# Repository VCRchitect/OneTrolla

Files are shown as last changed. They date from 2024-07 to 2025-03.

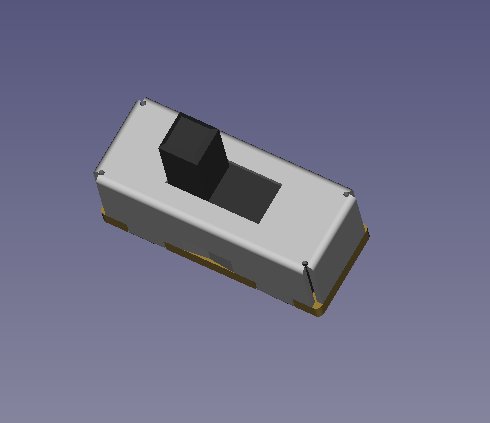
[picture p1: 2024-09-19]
KiCad Files/3D Models/ss12d00-1.snapshot.10/SS12D00 view 2.jpg

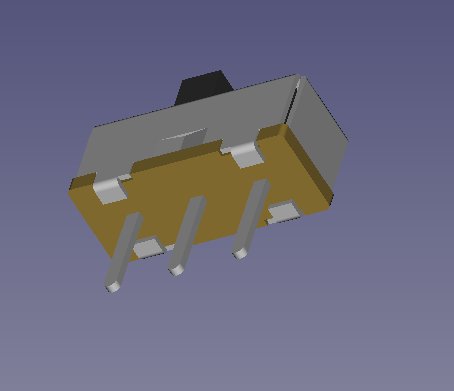
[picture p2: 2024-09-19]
KiCad Files/3D Models/ss12d00-1.snapshot.10/SS12D00 view3.jpg

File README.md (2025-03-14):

This is an ongoing project that aims to create a cheap, easy-to-use controller for those that have the usage of only one hand. 

The controller uses a custom circuit board that is paired with an Arduino Pro Micro and an MPU6050 Accelerometer. It has full compatibility as a wired controller for the Nintendo Switch, PC (including STEAM), Steam Deck, and Android phones (with an OTG cable or adapter).

HOW DO I USE IT?

The single analog stick on the device will act as either the left analog stick or right analog stick of a controller, depending on which mode you're in. The other stick will be controlled via motion and the accelerometer.

You can tilt the controller as if it were an arcade stick and it will act accordingly. I have inverted up and down on the left stick because, through my playtesting, it feels more natural to run forward by lifting up the controller. Not many games require running backwards, so pressing down is tilting forward, which feels less natural and, therefore, less used.

To quickly and easily swap which stick is which, press the button on the very bottom right of the controller (while you're looking directly at the buttons).

The buttons are arranged in a + pattern, just like most modern controllers. Top is X, left is Y, right is A, down is B, just like the Nintendo Switch. The two buttons below are the left trigger and right trigger.

In order to access the secondary buttons, hold down a primary button. X is Start, Y is R3, A is L3, B is Select, left trigger is LB, and right trigger is RB. If you are playing a game that requires holding a button that is considered a "primary" button, press it repeatedly and it will register as being consistently held.

To use the DPAD, press the physical analog stick in and tilt the analog stick in a direction to press the corresponding DPAD button.

The bottom left button (when you're looking directly at the buttons) is the HOME button. Tap it repeatedly to bring up the sleep menu. If you hold the HOME button until the LED changes, it will turn off the toggle function, making all the buttons function exactly the same as each other.

The toggles are for left trigger, right trigger, L3, and R3, which are buttons that are often held. Games like Zelda make this a necessity. Games like Mario 64 don't need the toggles, so they're easy to turn off.

Speaking of turning things off, it's easy to turn off the accelerometer and just use the stick for more basic games. You simply flip the physical toggle switch to the left of the B button.

If this isn't making as much sense as I'd like, review this image (some slight differences may be here because of more recent board revisions):

OneTrollaV3 Control Guide

If that still doesn't make any sense, please check out this vide (with timestamps!) that I made to explain everything and show off some gameplay:

https://youtu.be/NdQK882Hlzc?si=iMgsrqBHt_KTq-6e

Thanks for checking out the project!

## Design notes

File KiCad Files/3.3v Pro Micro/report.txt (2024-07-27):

Plotted to 'C:\Users\User\Desktop\Custom Duino\3.3v Pro Micro-F_Cu.gbr'.
Plotted to 'C:\Users\User\Desktop\Custom Duino\3.3v Pro Micro-B_Cu.gbr'.
Plotted to 'C:\Users\User\Desktop\Custom Duino\3.3v Pro Micro-F_Paste.gbr'.
Plotted to 'C:\Users\User\Desktop\Custom Duino\3.3v Pro Micro-B_Paste.gbr'.
Plotted to 'C:\Users\User\Desktop\Custom Duino\3.3v Pro Micro-F_Silkscreen.gbr'.
Plotted to 'C:\Users\User\Desktop\Custom Duino\3.3v Pro Micro-B_Silkscreen.gbr'.
Plotted to 'C:\Users\User\Desktop\Custom Duino\3.3v Pro Micro-F_Mask.gbr'.
Plotted to 'C:\Users\User\Desktop\Custom Duino\3.3v Pro Micro-B_Mask.gbr'.
Plotted to 'C:\Users\User\Desktop\Custom Duino\3.3v Pro Micro-Edge_Cuts.gbr'.
Created Gerber job file 'C:\Users\User\Desktop\Custom Duino\3.3v Pro Micro-job.gbrjob'.
Info: Done.

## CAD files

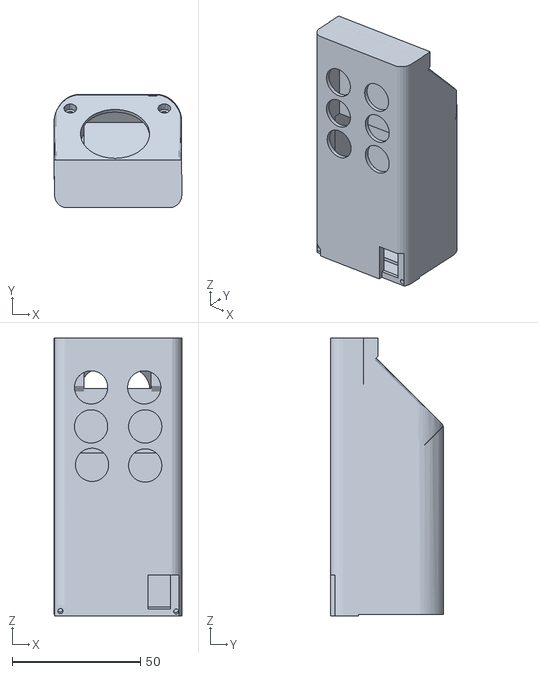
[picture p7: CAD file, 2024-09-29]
3D Print Files/Assembled Shell Render.stl
49.9 x 44.2 x 108.6

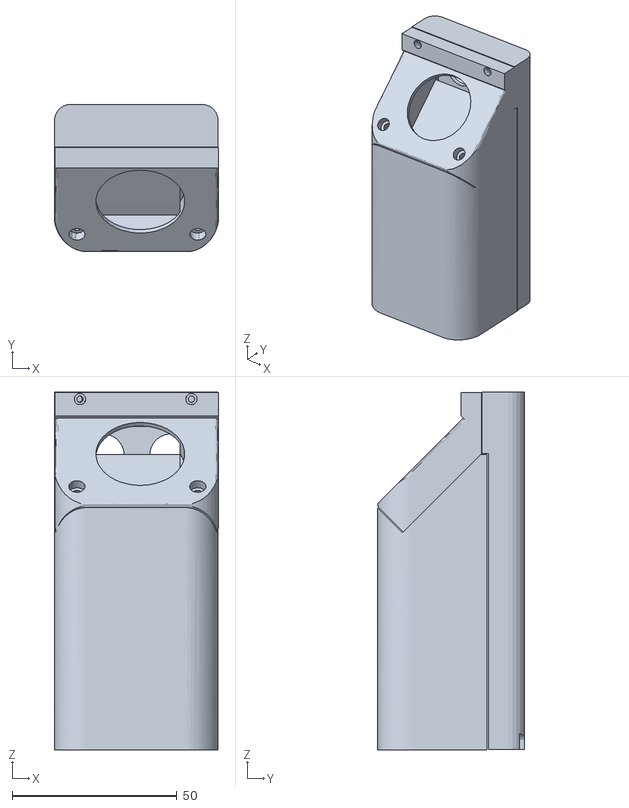
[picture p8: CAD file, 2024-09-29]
3D Print Files/Full Render.stl
49.8 x 44.6 x 108.7

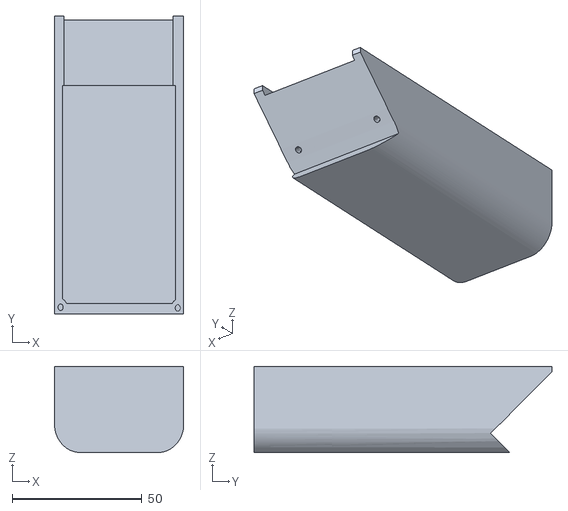
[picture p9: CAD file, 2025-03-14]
3D Print Files/OneTrollaV4 Back Plate.stl
49.8 x 114.9 x 33.2

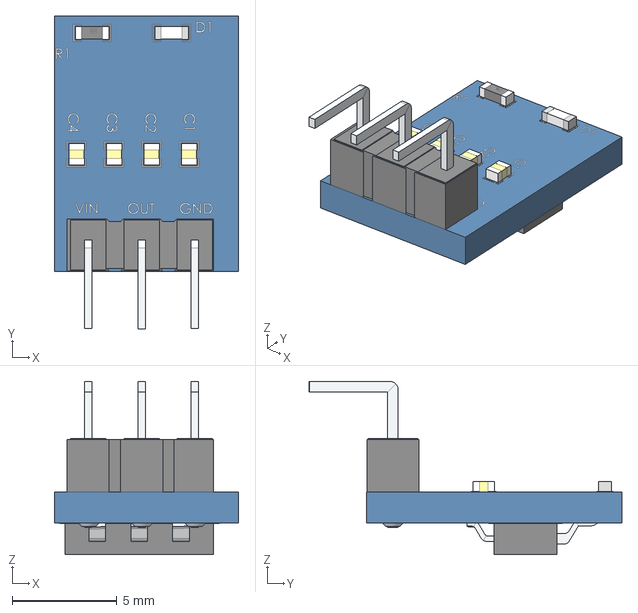
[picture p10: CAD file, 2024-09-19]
KiCad Files/3D Models/ams1117-1.snapshot.3/Regulador AMS1117 5V a 3.step
8.80 x 14.9 x 8.28 mm

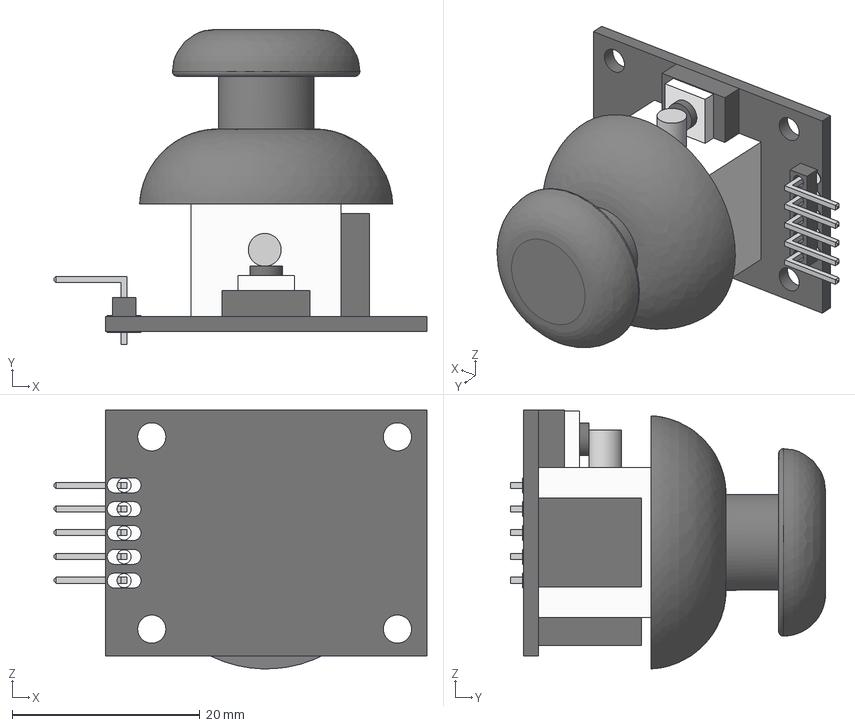
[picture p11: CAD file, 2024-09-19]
KiCad Files/3D Models/joy-stick-4.snapshot.1/joy_stick_a2/joy_stick_a2.iges
39.8 x 33.6 x 27.6 mm

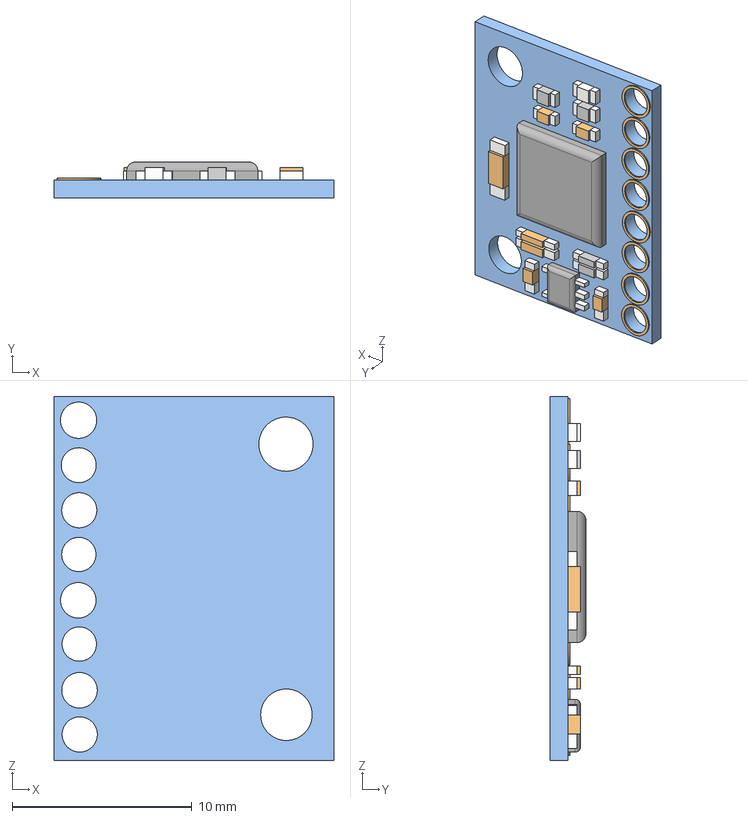
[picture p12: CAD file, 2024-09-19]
KiCad Files/3D Models/mpu6050-8.snapshot.1/MPU6050 v2.step
15.6 x 2.00 x 20.3 mm

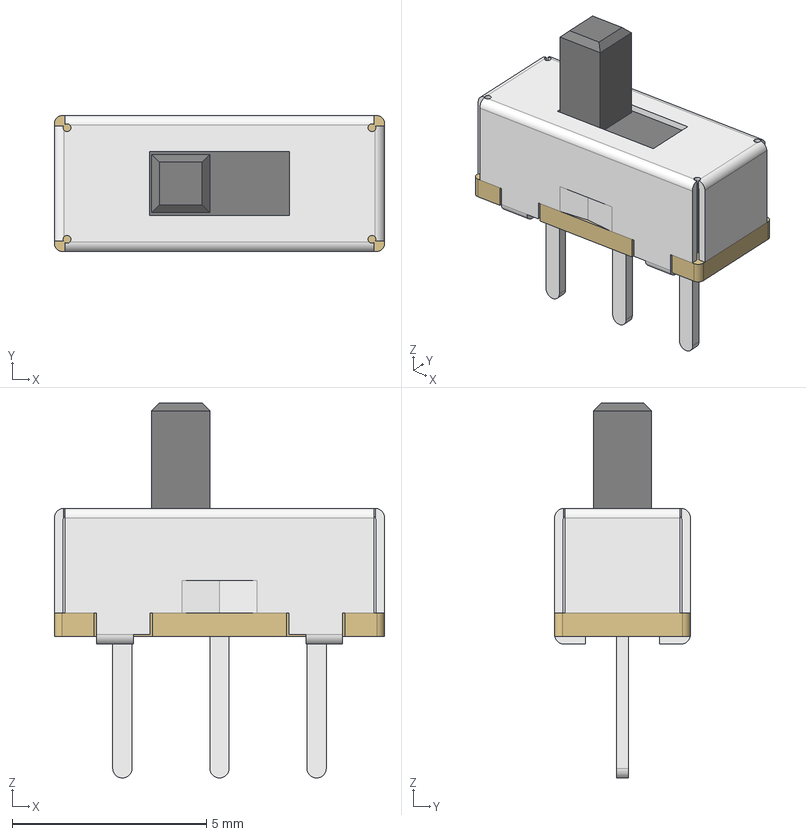
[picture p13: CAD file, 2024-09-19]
KiCad Files/3D Models/ss12d00-1.snapshot.10/SPDT slide switch SS12D00.step
8.50 x 3.50 x 9.66 mm

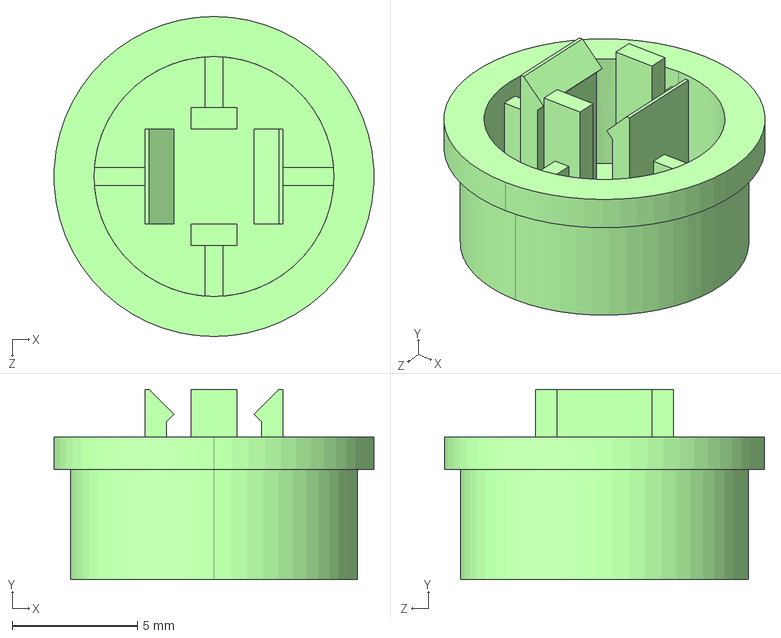
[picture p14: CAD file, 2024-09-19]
KiCad Files/3D Models/Tactile Push Button B3F-405 12X12x7.3mm with Cap/Tactile Button Cap for B3F-4055 12X12X7.3MM.STEP
12.8 x 7.60 x 12.8 mm

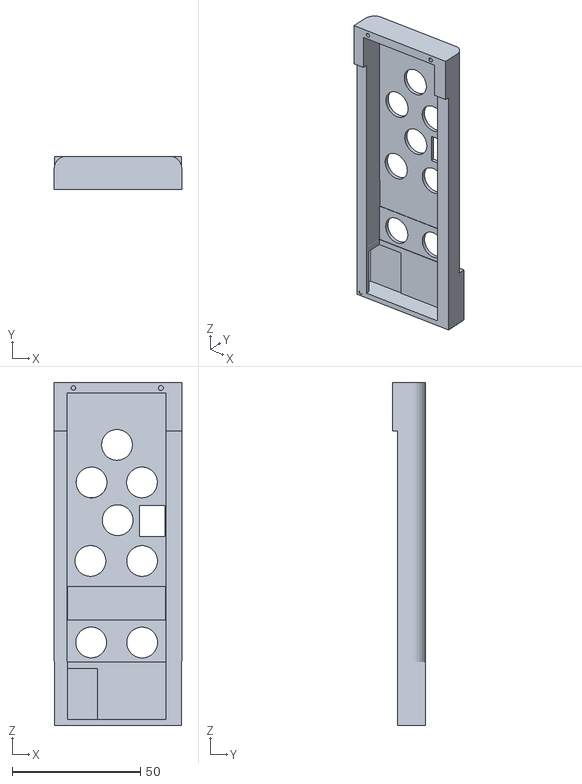
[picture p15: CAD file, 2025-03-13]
3D Print Files/OneTrollaV4 Front Plate.stl
49.8 x 12.8 x 133.5

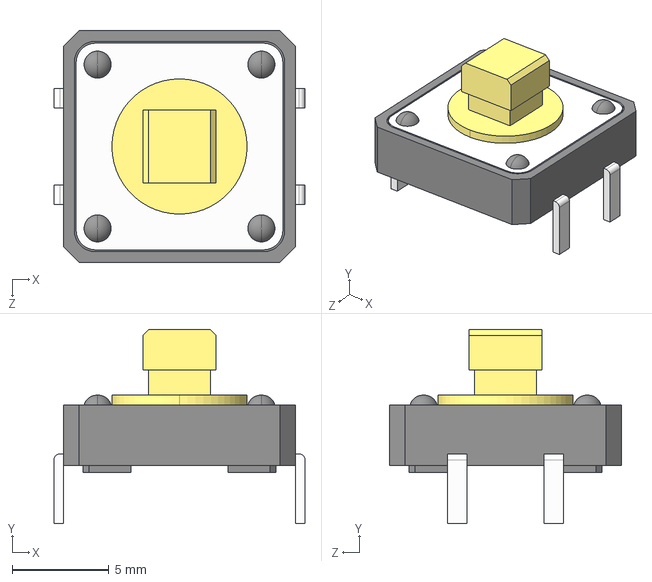
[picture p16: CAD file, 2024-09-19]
KiCad Files/3D Models/Tactile Push Button B3F-405 12X12x7.3mm with Cap/Tactile Push Button B3F-405 12X12x7.3mm.STEP
13.0 x 10.1 x 12.0 mm

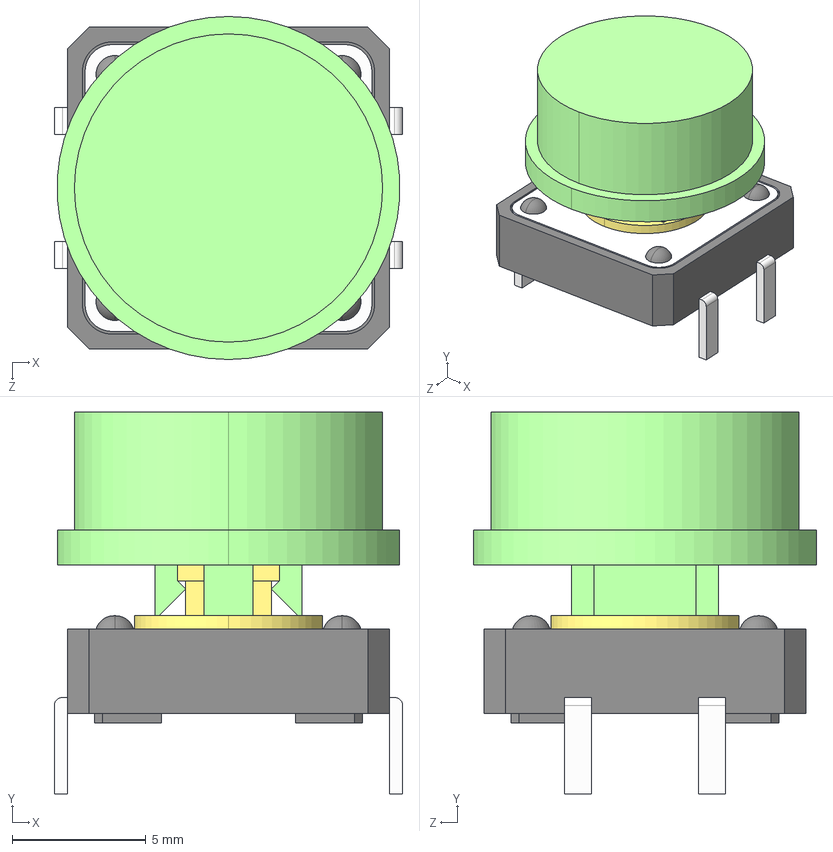
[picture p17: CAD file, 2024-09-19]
KiCad Files/3D Models/Tactile Push Button B3F-405 12X12x7.3mm with Cap/Push Button B3F-4055 with Cap.STEP
13.0 x 14.3 x 12.8 mm
Кнопка12х12х7,3
Tactile Button Caps for B3F-4055 12X12X7.3MM

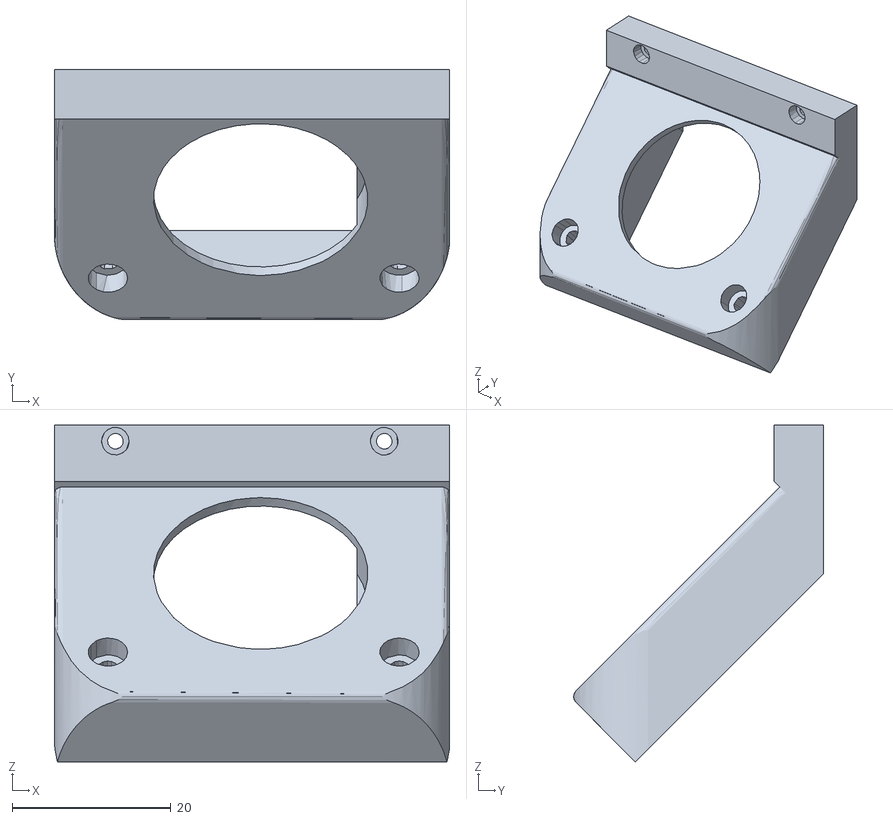
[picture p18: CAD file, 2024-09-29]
3D Print Files/OneTrollaV4 Joy Plate.stl
49.8 x 31.5 x 42.4

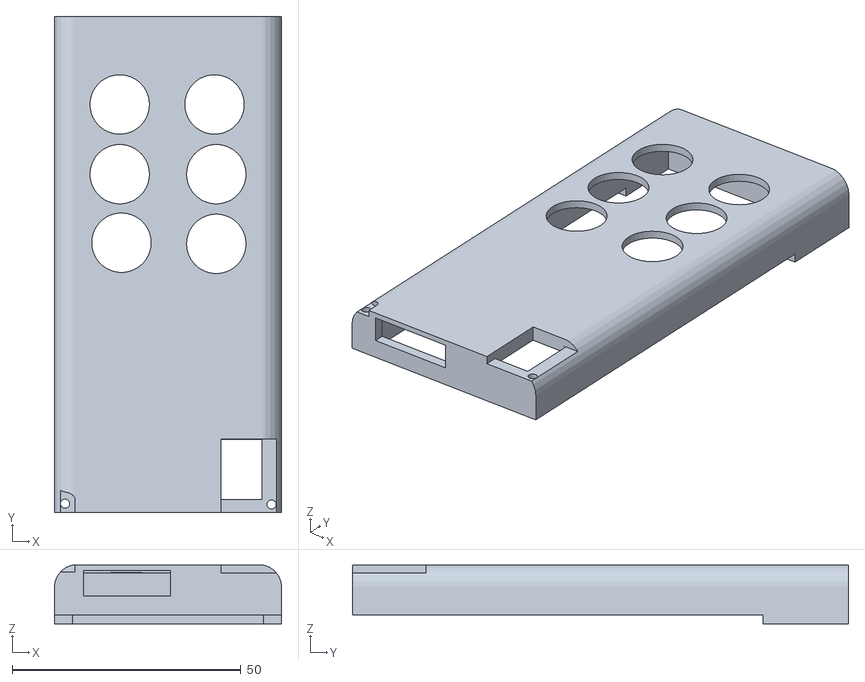
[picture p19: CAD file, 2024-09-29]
3D Print Files/Front Plate to be Edited.stl
49.8 x 108.5 x 12.9

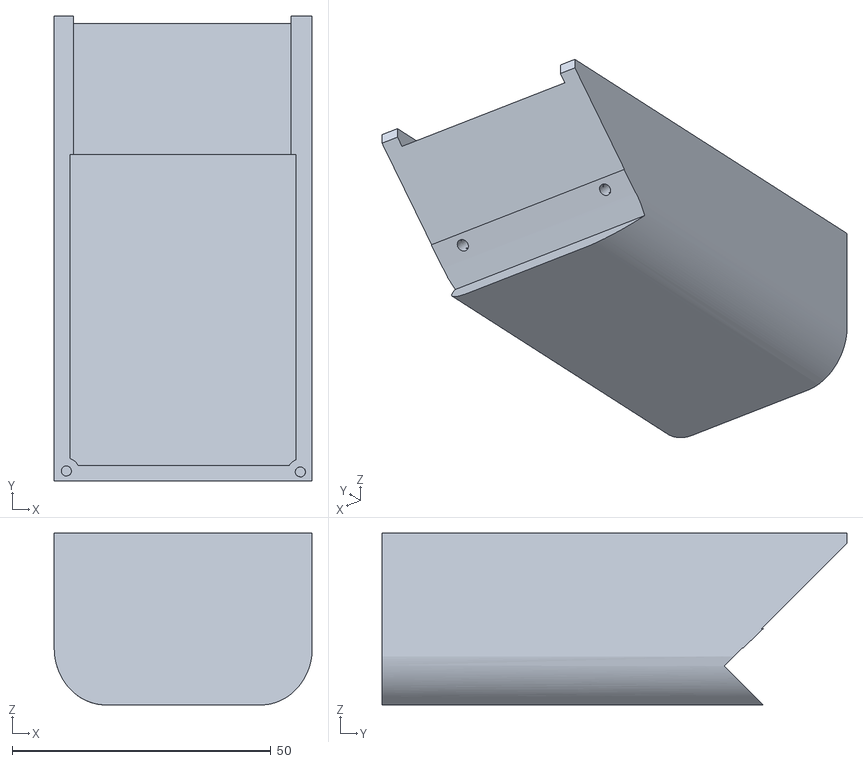
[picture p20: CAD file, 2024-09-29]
3D Print Files/Back Plate Paragon.stl
49.8 x 89.8 x 33.2

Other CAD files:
KiCad Files/3D Models/joy-stick-4.snapshot.1/joy_stick_a2/joy_stick_2a.step
KiCad Files/3D Models/Tactile Push Button B3F-405 12X12x7.3mm with Cap/Tactile Button Caps for B3F-4055 12X12X7.3MM.SLDPRT
KiCad Files/3D Models/Tactile Push Button B3F-405 12X12x7.3mm with Cap/Push Button B3F-4055 with Cap.SLDASM
KiCad Files/3D Models/Tactile Push Button B3F-405 12X12x7.3mm with Cap/Tactile Push Button B3F-405 12X12x7.3mm.SLDPRT
KiCad Files/3D Models/logic-level-converter-5v-to-3-3v-module-1.snapshot.1/Logi Level Converter.x_t
KiCad Files/3D Models/mpu6050-8.snapshot.1/MPU6050 v2.stl

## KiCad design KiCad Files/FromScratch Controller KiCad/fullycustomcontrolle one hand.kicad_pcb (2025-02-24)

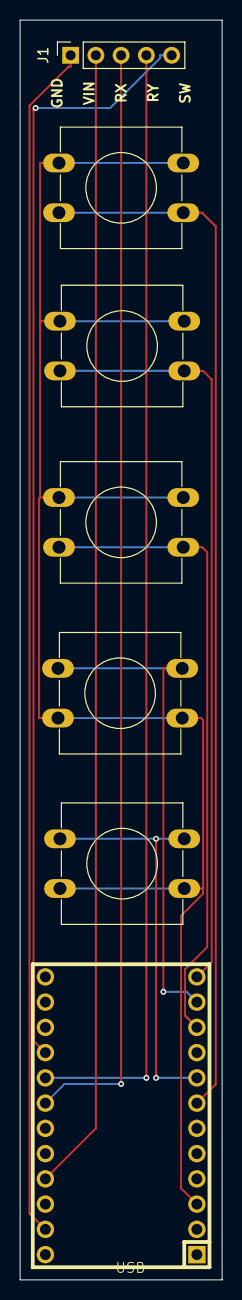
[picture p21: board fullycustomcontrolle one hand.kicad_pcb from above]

Board: 2 copper layers, 20.3 x 126.7 mm, 7 parts (0 on the bottom side), 11 nets.

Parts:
J1: Conn_01x05_Socket; PinSocket_1x05_P2.54mm_Vertical
SW2, SW3, SW4, SW6, SW7: SW_Omron_B3FS; SW_PUSH-12mm
U1: ProMicro; ARDUINO_PRO_MICRO

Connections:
unnamed: J1.1, U1.23 (GND)
unnamed: J1.2, U1.21 (VCC)
unnamed: J1.3, U1.18 (F6)
unnamed: J1.4, U1.17 (F7)
unnamed: J1.5, U1.16 (B1)
unnamed: SW2.2, SW3.2, SW4.2, SW6.2, SW7.2, U1.3 (GND)
unnamed: SW7.1, U1.11 (B4)
unnamed: SW3.1, U1.12 (B5)
unnamed: SW4.1, U1.8 (C6)
unnamed: SW2.1, U1.7 (D4)
unnamed: SW6.1, U1.10 (E6)

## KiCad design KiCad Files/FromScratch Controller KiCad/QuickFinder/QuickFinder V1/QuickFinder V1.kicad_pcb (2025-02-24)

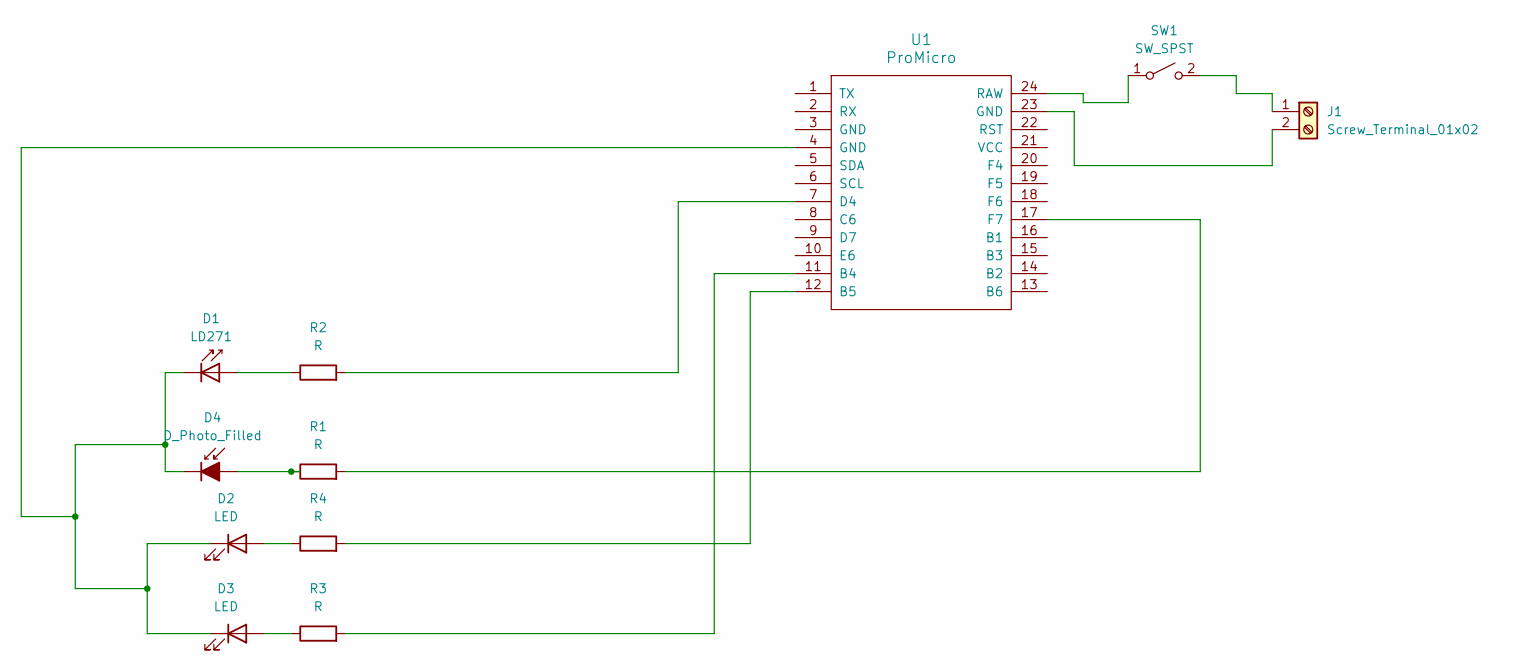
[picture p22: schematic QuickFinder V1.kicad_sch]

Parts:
D1: LD271; LED_D5.0mm_IRGrey
D2, D3: LED; LED_D3.0mm
D4: D_Photo_Filled; LED_D5.0mm
J1: Screw_Terminal_01x02; TerminalBlock_Phoenix_MPT-0,5-2-2.54_1x02_P2.54mm_Horizontal
R1, R2, R3, R4: R; R_Axial_DIN0207_L6.3mm_D2.5mm_P7.62mm_Horizontal
SW1: SW_SPST; SS12D00G SPDT Micro Switch
U1: ProMicro; ARDUINO_PRO_MICRO

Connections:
unnamed: D1.2 (A), R2.1
unnamed: D1.1 (K), D2.1 (K), D3.1 (K), D4.1 (K), U1.4 (GND)
unnamed: D2.2 (A), R4.1
unnamed: D3.2 (A), R3.1
unnamed: D4.2 (A), R1.1
unnamed: J1.1, SW1.2 (B)
unnamed: J1.2, U1.23 (GND)
unnamed: SW1.1 (A), U1.24 (RAW)
unnamed: R3.2, U1.11 (B4)
unnamed: R4.2, U1.12 (B5)
unnamed: R2.2, U1.7 (D4)
unnamed: R1.2, U1.17 (F7)

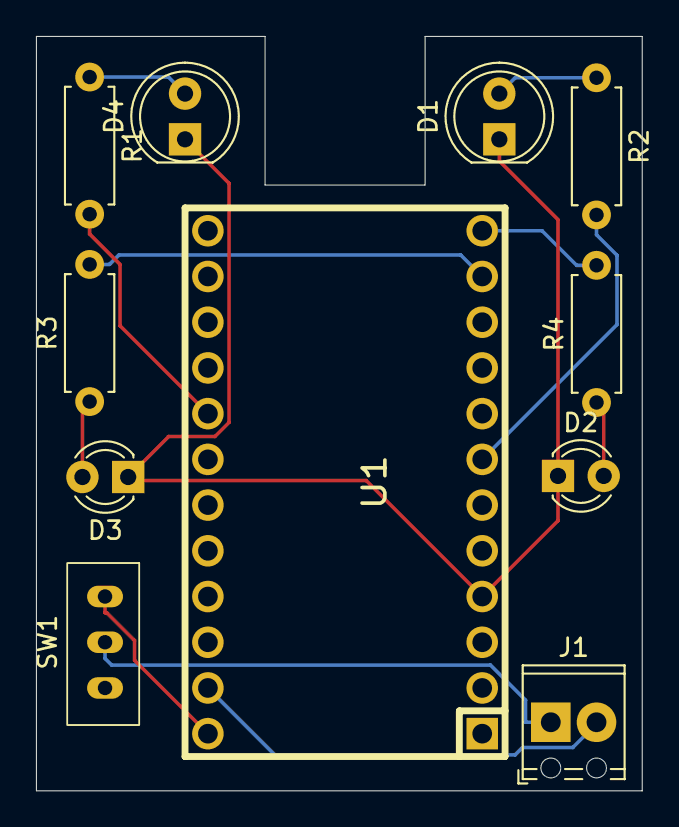
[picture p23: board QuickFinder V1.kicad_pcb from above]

Board: 2 copper layers, 33.7 x 41.9 mm, 11 parts (0 on the bottom side), 12 nets.

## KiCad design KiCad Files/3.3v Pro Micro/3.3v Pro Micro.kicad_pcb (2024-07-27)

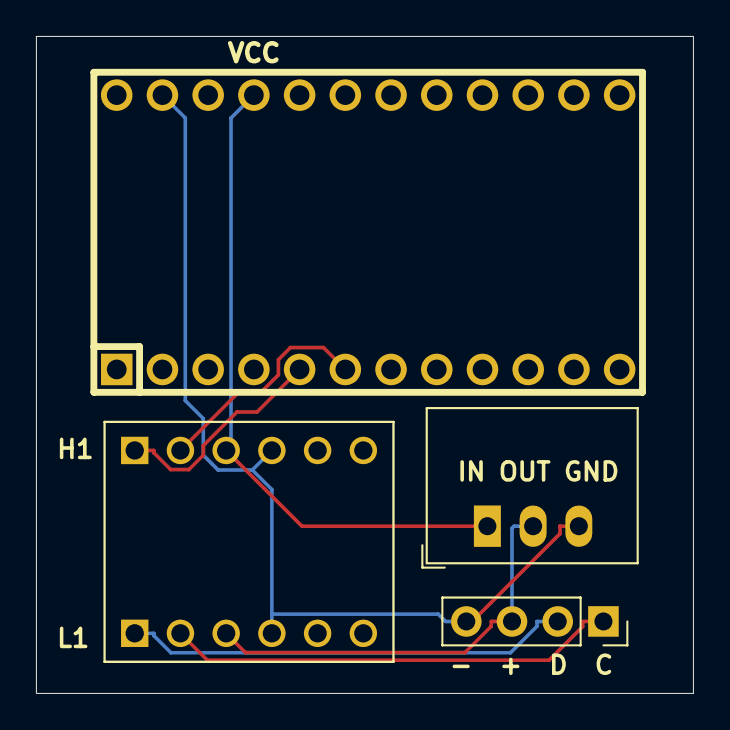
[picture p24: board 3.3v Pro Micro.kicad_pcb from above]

Board: 2 copper layers, 36.5 x 36.5 mm, 4 parts (0 on the bottom side), 7 nets.

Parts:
J1: Conn_01x04_Socket; PinSocket_1x04_P2.54mm_Vertical
U2: ProMicro; ARDUINO_PRO_MICRO
U3: BOB-12009; CONV_BOB-12009
U4: Converter_DCDC_RECOM_R-78E-0.5_THT

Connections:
unnamed: J1.1, U3.LV2
unnamed: J1.2, U3.LV1
unnamed: J1.3, U3.LV, U4.2 (OUT)
unnamed: J1.4, U2.23 (GND), U3.GND_1 (GND), U3.GND_2 (GND), U4.3 (GND)
unnamed: U2.6 (SCL), U3.HV2
unnamed: U2.5 (SDA), U3.HV1
unnamed: U2.21 (VCC), U3.HV, U4.1 (IN)

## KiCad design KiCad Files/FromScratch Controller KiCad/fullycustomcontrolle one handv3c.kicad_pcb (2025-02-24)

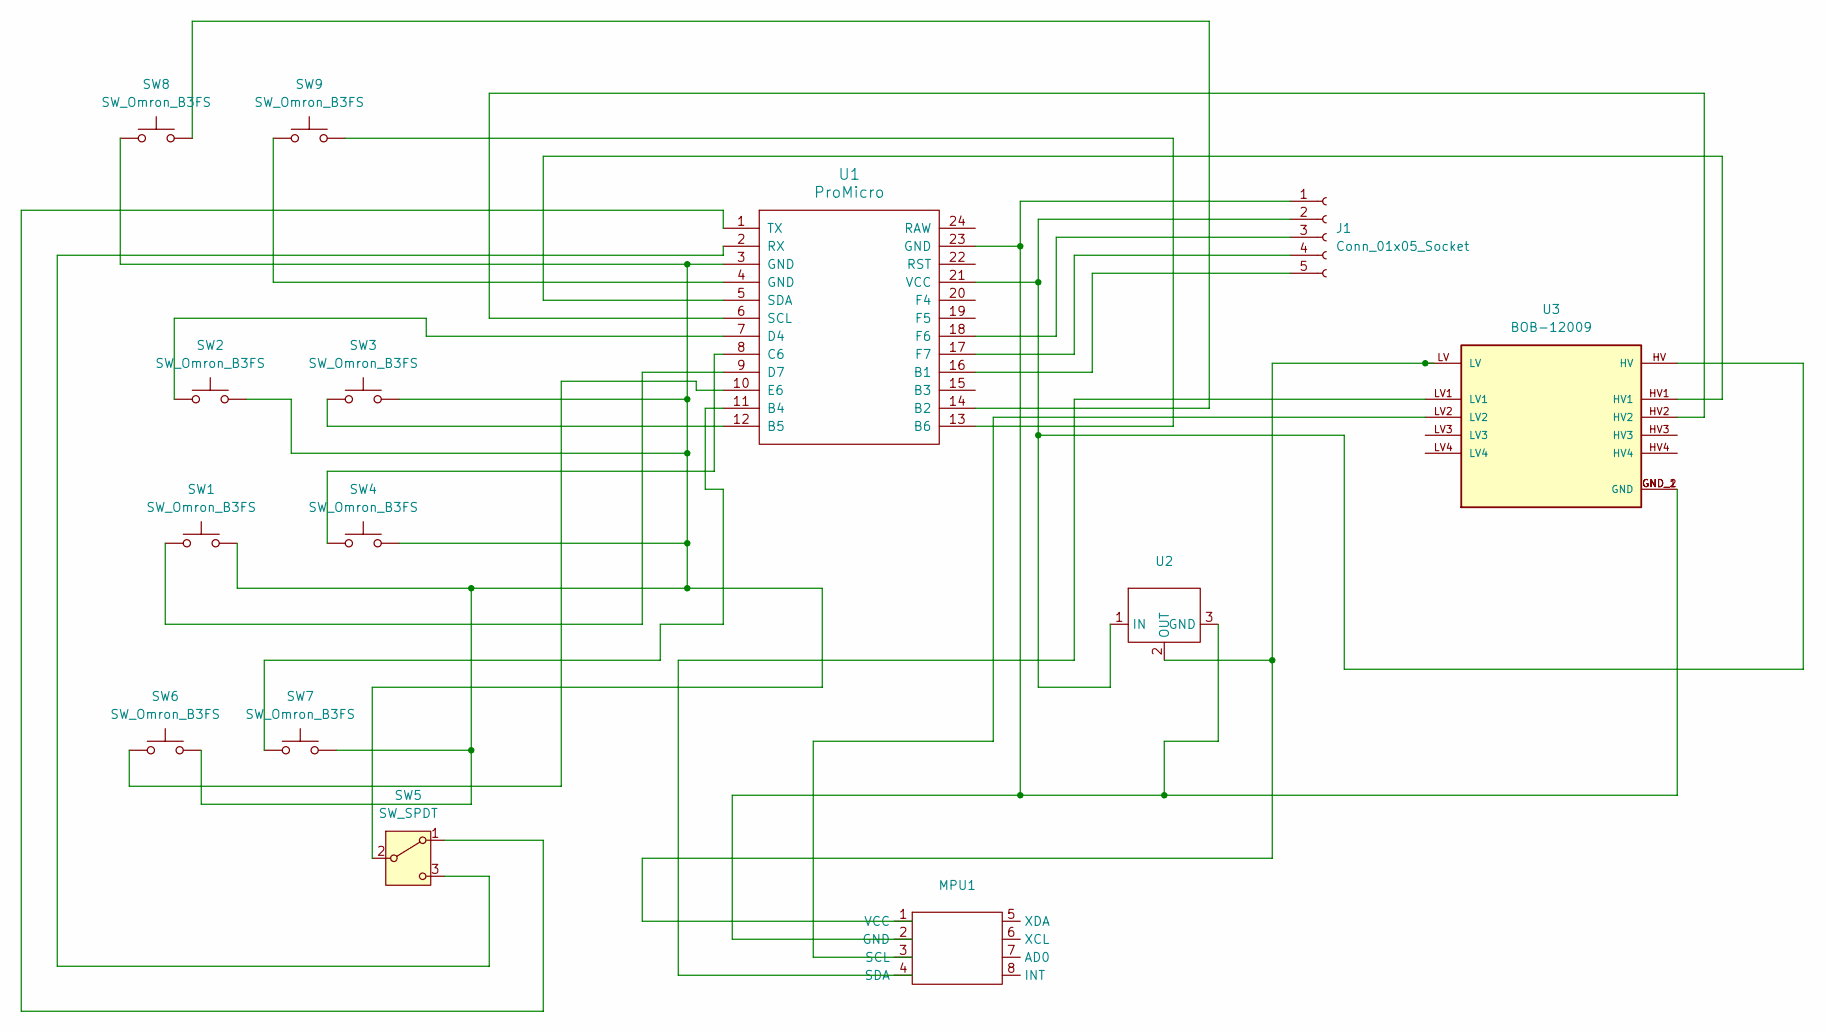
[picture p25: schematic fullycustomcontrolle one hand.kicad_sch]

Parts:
J1: Conn_01x05_Socket; PinSocket_1x05_P2.54mm_Vertical
MPU1: MPU6050 Accelerometer
SW1, SW2, SW3, SW4, SW6, SW7, SW8, SW9: SW_Omron_B3FS; SW_PUSH-12mm
SW5: SW_SPDT; SS12D00G SPDT Micro Switch
U1: ProMicro; ARDUINO_PRO_MICRO
U2: 3.3v InOutGnd Voltage Regulator
U3: BOB-12009; CONV_BOB-12009; PARTREV 01

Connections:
unnamed: J1.1, MPU1.2 (GND), U1.23 (GND), U2.3 (GND), U3.GND_1 (GND), U3.GND_2 (GND)
unnamed: J1.2, U1.21 (VCC), U2.1 (IN), U3.HV
unnamed: J1.3, U1.18 (F6)
unnamed: J1.4, U1.17 (F7)
unnamed: J1.5, U1.16 (B1)
unnamed: MPU1.3 (SCL), U3.LV2
unnamed: MPU1.4 (SDA), U3.LV1
unnamed: MPU1.1 (VCC), U2.2 (OUT), U3.LV
unnamed: SW5.1 (A), U1.1 (TX)
unnamed: SW1.2, SW2.2, SW3.2, SW4.2, SW5.2 (B), SW6.2, SW7.2, SW8.1, U1.3 (GND)
unnamed: SW5.3 (C), U1.2 (RX)
unnamed: SW9.1, U1.4 (GND)
unnamed: SW8.2, U1.14 (B2)
unnamed: SW7.1, U1.11 (B4)
unnamed: SW3.1, U1.12 (B5)
unnamed: SW9.2, U1.13 (B6)
unnamed: SW4.1, U1.8 (C6)
unnamed: SW2.1, U1.7 (D4)
unnamed: SW1.1, U1.9 (D7)
unnamed: SW6.1, U1.10 (E6)
unnamed: U1.6 (SCL), U3.HV2
unnamed: U1.5 (SDA), U3.HV1

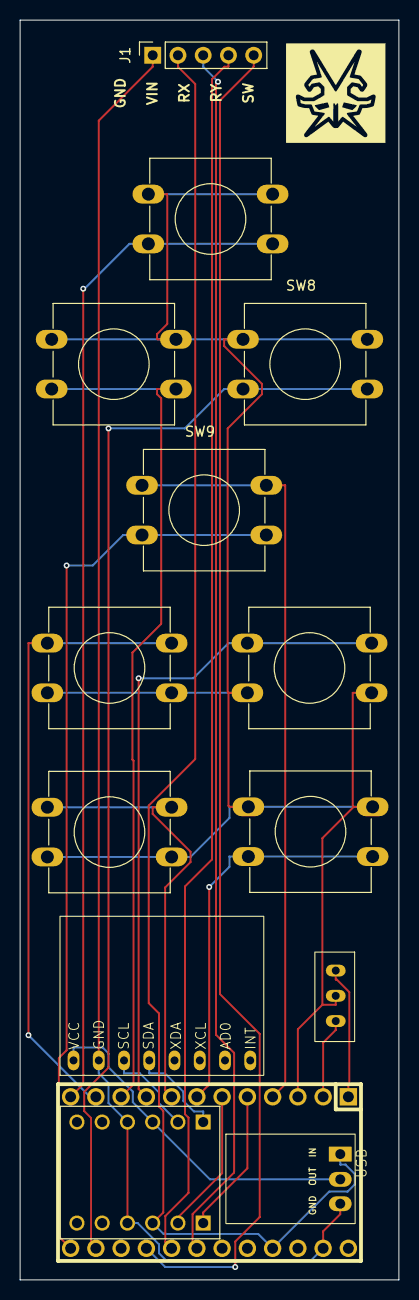
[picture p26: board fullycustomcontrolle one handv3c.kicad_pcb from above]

Board: 2 copper layers, 38.1 x 126.7 mm, 14 parts (0 on the bottom side), 22 nets.

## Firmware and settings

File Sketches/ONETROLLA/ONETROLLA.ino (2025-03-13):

#define DB_ACTIVE 0

#include <MPU6050.h>
#include <Wire.h>
#include "LUFAConfig.h"
#include <LUFA.h>
#include "Joystick.h"
#define BOUNCE_WITH_PROMPT_DETECTION
#include <Bounce2.h>

#define MILLIDEBOUNCE 1  // Debounce time in milliseconds
#define pinOBLED 17      // Onboard LED pin

#define joyX A0
#define joyY A1

MPU6050 mpu;           // Create an instance of the MPU6050
bool altmode = false;  // Global altmode variable

// --- Global flag for homeheld mode ---
// When false, buttons L, A, and Y use toggle logic;
// when true, a held press sends the alternate (momentary) output.
bool homeheld = false;
bool homeheldToggleHandled = false;  // Prevent multiple toggles per long press

// --- Update button indices and array sizes ---
#define BUTTON1 0  // A button (normal: sends A; long press toggles L3)
#define BUTTON2 1  // B button (long press sends SELECT)
#define BUTTON3 2  // X button (long press sends START)
#define BUTTON4 3  // Y button (normal: sends Y; long press toggles R3)
#define BUTTON5 4  // Used for DPAD mode (unchanged)
#define SHIFT1 5   // L button (short press toggles ZL, long press = LB)
#define SHIFT2 6   // R button (short press toggles ZR, long press = RB)
#define BUTTON6 7  // HOME button (short press = HOME, long press toggles homeheld)
#define BUTTON7 8  // Button7 toggles altmode

byte buttonStatus[9];  // Now 9 entries

// --- Button state machine indices ---
#define BUTTON_SM_1 0  // For A button (L3 toggle in default mode)
#define BUTTON_SM_2 1  // For B button (long press = SELECT)
#define BUTTON_SM_3 2  // For X button (long press = START)
#define BUTTON_SM_4 3  // For Y button (R3 toggle in default mode)
#define SHIFT_SM_1 4   // For SHIFT1 (L button)
#define SHIFT_SM_2 5   // For SHIFT2 (R button)
#define BUTTON_SM_6 6  // For HOME button
#define BUTTON_SM_7 7  // For altmode toggle

// --- Button mask definitions ---
#define DPAD_NOTHING_MASK_ON 0x08
#define DPAD_UP_MASK_ON 0x00
#define DPAD_UPRIGHT_MASK_ON 0x01
#define DPAD_RIGHT_MASK_ON 0x02
#define DPAD_DOWNRIGHT_MASK_ON 0x03
#define DPAD_DOWN_MASK_ON 0x04
#define DPAD_DOWNLEFT_MASK_ON 0x05
#define DPAD_LEFT_MASK_ON 0x06
#define DPAD_UPLEFT_MASK_ON 0x07
#define A_MASK_ON 0x04
#define B_MASK_ON 0x02
#define X_MASK_ON 0x08
#define Y_MASK_ON 0x01
#define LB_MASK_ON 0x10
#define RB_MASK_ON 0x20
#define ZL_MASK_ON 0x40
#define ZR_MASK_ON 0x80
#define L3_MASK_ON 0x400
#define R3_MASK_ON 0x800
#define START_MASK_ON 0x200
#define SELECT_MASK_ON 0x100
#define HOME_MASK_ON 0x1000

// --- Define pins for buttons and shifts ---
#define PIN_BUTTON1 16
#define PIN_BUTTON2 10
#define PIN_BUTTON3 9
#define PIN_BUTTON4 7
#define PIN_BUTTON5 15
#define PIN_BUTTON6 5
#define PIN_BUTTON7 4
#define PIN_SHIFT1 6
#define PIN_SHIFT2 8
#define PIN_ALT_MODE_0 0  // When low: force active stick axes to neutral (128)
#define PIN_ALT_MODE_1 1  // When low: accelerometer functions normally

// --- Create Bounce objects ---
Bounce button1 = Bounce();
Bounce button2 = Bounce();
Bounce button3 = Bounce();
Bounce button4 = Bounce();
Bounce button5 = Bounce();
Bounce shift1 = Bounce();
Bounce shift2 = Bounce();
Bounce button6 = Bounce();
Bounce button7 = Bounce();

// --- State machine definitions ---
enum ButtonState {
  BUTTON_IDLE,
  BUTTON_PRESSED,
  BUTTON_LONG_PRESSED
};
ButtonState buttonStates[8] = {
  BUTTON_IDLE, BUTTON_IDLE, BUTTON_IDLE, BUTTON_IDLE,
  BUTTON_IDLE, BUTTON_IDLE, BUTTON_IDLE, BUTTON_IDLE
};

enum ButtonAction {
  ACTION_NONE,
  ACTION_SHORT_PRESS,
  ACTION_SHORT_PRESS_HOLDING,
  ACTION_SHORT_RELEASE
};
ButtonAction actionNeeded[8] = {
  ACTION_NONE, ACTION_NONE, ACTION_NONE, ACTION_NONE,
  ACTION_NONE, ACTION_NONE, ACTION_NONE, ACTION_NONE
};

unsigned long buttonPressStartTime[8] = { 0,0,0,0,0,0,0,0 };
unsigned long pressStartTime[8]       = { 0,0,0,0,0,0,0,0 };

// --- Variables for toggle logic (default mode) ---
bool shift1ZLToggle = false;
bool shift1ToggleHandled = false;
bool shift2ZRToggle = false;       // <-- New toggle variable for ZR
bool shift2ToggleHandled = false;  // <-- Helper to avoid repeated toggles
bool aToggle = false;
bool aToggleHandled = false;
bool yToggle = false;
bool yToggleHandled = false;

void setupPins() {
  button1.attach(PIN_BUTTON1, INPUT_PULLUP);
  button2.attach(PIN_BUTTON2, INPUT_PULLUP);
  button3.attach(PIN_BUTTON3, INPUT_PULLUP);
  button4.attach(PIN_BUTTON4, INPUT_PULLUP);
  button5.attach(PIN_BUTTON5, INPUT_PULLUP);
  shift1.attach(PIN_SHIFT1, INPUT_PULLUP);
  shift2.attach(PIN_SHIFT2, INPUT_PULLUP);
  button6.attach(PIN_BUTTON6, INPUT_PULLUP);
  button7.attach(PIN_BUTTON7, INPUT_PULLUP);

  button1.interval(MILLIDEBOUNCE);
  button2.interval(MILLIDEBOUNCE);
  button3.interval(MILLIDEBOUNCE);
  button4.interval(MILLIDEBOUNCE);
  button5.interval(MILLIDEBOUNCE);
  shift1.interval(MILLIDEBOUNCE);
  shift2.interval(MILLIDEBOUNCE);
  button6.interval(MILLIDEBOUNCE);
  button7.interval(MILLIDEBOUNCE);

  pinMode(pinOBLED, OUTPUT);
  digitalWrite(pinOBLED, LOW);

  // Set up the accelerometer control pins
  pinMode(PIN_ALT_MODE_0, INPUT_PULLUP);
  pinMode(PIN_ALT_MODE_1, INPUT_PULLUP);
}

void setup() {
  setupPins();

  Wire.begin();
  mpu.initialize();
  if (!mpu.testConnection()) {
    while (true) {
      digitalWrite(pinOBLED, !digitalRead(pinOBLED));
      delay(500);
    }
  }

  SetupHardware();
  GlobalInterruptEnable();
}

void loop() {
  readAnalogStick();
  readMPU6050();
  readButtons();
  processButtons();
  HID_Task();
  USB_USBTask();
}

void readAnalogStick() {
  const int deadzone = 15;
  int xValue = analogRead(joyX);
  int yValue = analogRead(joyY);

  if (abs(xValue - 512) < deadzone) xValue = 512;
  if (abs(yValue - 512) < deadzone) yValue = 512;

  // DPAD mode if button5 is pressed
  if (buttonStatus[BUTTON5] == LOW) {
    // Map analog to DPAD
    if (xValue < 341) {
      if (yValue < 341) ReportData.HAT = DPAD_UPRIGHT_MASK_ON;
      else if (yValue > 682) ReportData.HAT = DPAD_DOWNRIGHT_MASK_ON;
      else ReportData.HAT = DPAD_RIGHT_MASK_ON;
    } else if (xValue > 682) {
      if (yValue < 341) ReportData.HAT = DPAD_UPLEFT_MASK_ON;
      else if (yValue > 682) ReportData.HAT = DPAD_DOWNLEFT_MASK_ON;
      else ReportData.HAT = DPAD_LEFT_MASK_ON;
    } else {
      if (yValue < 341) ReportData.HAT = DPAD_UP_MASK_ON;
      else if (yValue > 682) ReportData.HAT = DPAD_DOWN_MASK_ON;
      else ReportData.HAT = DPAD_NOTHING_MASK_ON;
    }
    // In DPAD mode, force whichever stick is active to neutral
    if (altmode) {
      ReportData.LX = 128;
      ReportData.LY = 128;
    } else {
      ReportData.RX = 128;
      ReportData.RY = 128;
    }
  } else {
    // Normal analog mode
    ReportData.HAT = DPAD_NOTHING_MASK_ON;
    if (altmode) {
      ReportData.LX = map(xValue, 0, 1023, 255, 0);
      ReportData.LY = map(yValue, 0, 1023, 0, 255);
    } else {
      ReportData.RX = map(xValue, 0, 1023, 255, 0);
      ReportData.RY = map(yValue, 0, 1023, 0, 255);
    }
  }
}

void readMPU6050() {
  // If PIN_ALT_MODE_0 is low, force stick axes to neutral
  if (digitalRead(PIN_ALT_MODE_0) == LOW) {
    if (altmode || buttonStatus[BUTTON5] == LOW) {
      ReportData.RX = 128;
      ReportData.RY = 128;
    } else {
      ReportData.LX = 128;
      ReportData.LY = 128;
    }
    return;
  }

  int16_t ax, ay, az;
  mpu.getAcceleration(&ax, &ay, &az);

  const int16_t deadzoneThreshold = 9001;
  const int16_t deadzoneThreshold2 = 9000;
  int16_t adjustedX = -ay;
  int16_t adjustedY = -az;

  static float smoothedX = 0;
  static float smoothedY = 0;
  const float alpha = 0.1;

  // Initialize smoothing if first time
  if (smoothedX == 0 && smoothedY == 0) {
    smoothedX = adjustedX;
    smoothedY = adjustedY;
  }

  smoothedX = alpha * adjustedX + (1 - alpha) * smoothedX;
  smoothedY = alpha * adjustedY + (1 - alpha) * smoothedY;

  if (altmode || buttonStatus[BUTTON5] == LOW) {
    // A bit bigger range for Right stick
    ReportData.RX = (abs(smoothedX) > deadzoneThreshold)
      ? map(constrain((int32_t)smoothedX, -10000, 10000), -10000, 10000, 0, 255)
      : 128;
    ReportData.RY = (abs(smoothedY) > deadzoneThreshold)
      ? map(constrain((int32_t)smoothedY, -10000, 10000), -10000, 10000, 0, 255)
      : 128;
  } else {
    // Slightly narrower range for Left stick
    ReportData.LX = (abs(smoothedX) > deadzoneThreshold2)
      ? map(constrain((int32_t)smoothedX, -8000, 8000), -8000, 8000, 0, 255)
      : 128;
    ReportData.LY = (abs(smoothedY) > deadzoneThreshold2)
      ? map(constrain((int32_t)smoothedY, -6000, 6000), -6000, 6000, 0, 255)
      : 128;
  }
}

void readButtons() {
  button1.update();
  button2.update();
  button3.update();
  button4.update();
  button5.update();
  shift1.update();
  shift2.update();
  button6.update();
  button7.update();

  buttonStatus[BUTTON1] = button1.read();
  buttonStatus[BUTTON2] = button2.read();
  buttonStatus[BUTTON3] = button3.read();
  buttonStatus[BUTTON4] = button4.read();
  buttonStatus[BUTTON5] = button5.read();
  buttonStatus[SHIFT1] = shift1.read();
  buttonStatus[SHIFT2] = shift2.read();
  buttonStatus[BUTTON6] = button6.read();
  buttonStatus[BUTTON7] = button7.read();

  // Update state machines for relevant buttons
  handleButtonPress(button1, BUTTON_SM_1);
  handleButtonPress(button2, BUTTON_SM_2);
  handleButtonPress(button3, BUTTON_SM_3);
  handleButtonPress(button4, BUTTON_SM_4);
  handleButtonPress(shift1, SHIFT_SM_1);
  handleButtonPress(shift2, SHIFT_SM_2);
  handleButtonPress(button6, BUTTON_SM_6);
  handleButtonPress(button7, BUTTON_SM_7);
}

void handleButtonPress(Bounce &button, int idx) {
  switch (buttonStates[idx]) {
    case BUTTON_IDLE:
      if (button.fell()) {
        buttonPressStartTime[idx] = millis();
        buttonStates[idx] = BUTTON_PRESSED;
      }
      break;

    case BUTTON_PRESSED:
      if (button.read() == LOW) {
        // Check if we've reached the long-press threshold
        if (millis() - buttonPressStartTime[idx] >= 500) {
          buttonStates[idx] = BUTTON_LONG_PRESSED;
        }
      } else if (button.rose()) {
        // It was a short press
        buttonStates[idx] = BUTTON_IDLE;
        actionNeeded[idx] = ACTION_SHORT_PRESS;
      }
      break;

    case BUTTON_LONG_PRESSED:
      // Once in long-press state, remain until button is released
      if (button.read() == HIGH) {
        buttonStates[idx] = BUTTON_IDLE;
      }
      break;
  }
}

void processButtons() {
  // Clear previous button states
  ReportData.Button = 0;

  // Process each button state machine
  for (int i = BUTTON_SM_1; i <= BUTTON_SM_7; i++) {
    // BUTTON_SM_1: A button (toggles L3 in default mode)
    if (i == BUTTON_SM_1) {
      if (!homeheld) {
        // Default mode: long press toggles L3; short press => A
        if (buttonStates[BUTTON_SM_1] == BUTTON_LONG_PRESSED) {
          if (!aToggleHandled) {
            aToggle = !aToggle;
            aToggleHandled = true;
          }
        } else {
          aToggleHandled = false;
          if (actionNeeded[BUTTON_SM_1] == ACTION_SHORT_PRESS) {
            ReportData.Button |= A_MASK_ON;
            pressStartTime[BUTTON_SM_1] = millis();
            actionNeeded[BUTTON_SM_1] = ACTION_SHORT_PRESS_HOLDING;
          } else if (actionNeeded[BUTTON_SM_1] == ACTION_SHORT_PRESS_HOLDING) {
            ReportData.Button |= A_MASK_ON;
            if (millis() - pressStartTime[BUTTON_SM_1] >= 255)
              actionNeeded[BUTTON_SM_1] = ACTION_SHORT_RELEASE;
          } else if (actionNeeded[BUTTON_SM_1] == ACTION_SHORT_RELEASE) {
            actionNeeded[BUTTON_SM_1] = ACTION_NONE;
          }
        }
      } else {
        // homeheld: long press => momentary L3, short press => A
        if (buttonStates[BUTTON_SM_1] == BUTTON_LONG_PRESSED) {
          ReportData.Button |= L3_MASK_ON;
        } else {
          if (actionNeeded[BUTTON_SM_1] == ACTION_SHORT_PRESS) {
            ReportData.Button |= A_MASK_ON;
            pressStartTime[BUTTON_SM_1] = millis();
            actionNeeded[BUTTON_SM_1] = ACTION_SHORT_PRESS_HOLDING;
          } else if (actionNeeded[BUTTON_SM_1] == ACTION_SHORT_PRESS_HOLDING) {
            ReportData.Button |= A_MASK_ON;
            if (millis() - pressStartTime[BUTTON_SM_1] >= 255)
              actionNeeded[BUTTON_SM_1] = ACTION_SHORT_RELEASE;
          } else if (actionNeeded[BUTTON_SM_1] == ACTION_SHORT_RELEASE) {
            actionNeeded[BUTTON_SM_1] = ACTION_NONE;
          }
        }
      }
    }
    // BUTTON_SM_2: B button
    else if (i == BUTTON_SM_2) {
      if (buttonStates[BUTTON_SM_2] == BUTTON_LONG_PRESSED) {
        ReportData.Button |= SELECT_MASK_ON;
      } else if (actionNeeded[BUTTON_SM_2] == ACTION_SHORT_PRESS) {
        ReportData.Button |= B_MASK_ON;
        pressStartTime[BUTTON_SM_2] = millis();
        actionNeeded[BUTTON_SM_2] = ACTION_SHORT_PRESS_HOLDING;
      } else if (actionNeeded[BUTTON_SM_2] == ACTION_SHORT_PRESS_HOLDING) {
        ReportData.Button |= B_MASK_ON;
        if (millis() - pressStartTime[BUTTON_SM_2] >= 255)
          actionNeeded[BUTTON_SM_2] = ACTION_SHORT_RELEASE;
      } else if (actionNeeded[BUTTON_SM_2] == ACTION_SHORT_RELEASE) {
        actionNeeded[BUTTON_SM_2] = ACTION_NONE;
      }
    }
    // BUTTON_SM_3: X button
    else if (i == BUTTON_SM_3) {
      if (buttonStates[BUTTON_SM_3] == BUTTON_LONG_PRESSED) {
        ReportData.Button |= START_MASK_ON;
      } else if (actionNeeded[BUTTON_SM_3] == ACTION_SHORT_PRESS) {
        ReportData.Button |= X_MASK_ON;
        pressStartTime[BUTTON_SM_3] = millis();
        actionNeeded[BUTTON_SM_3] = ACTION_SHORT_PRESS_HOLDING;
      } else if (actionNeeded[BUTTON_SM_3] == ACTION_SHORT_PRESS_HOLDING) {
        ReportData.Button |= X_MASK_ON;
        if (millis() - pressStartTime[BUTTON_SM_3] >= 255)
          actionNeeded[BUTTON_SM_3] = ACTION_SHORT_RELEASE;
      } else if (actionNeeded[BUTTON_SM_3] == ACTION_SHORT_RELEASE) {
        actionNeeded[BUTTON_SM_3] = ACTION_NONE;
      }
    }
    // BUTTON_SM_4: Y button (toggles R3 in default mode)
    else if (i == BUTTON_SM_4) {
      if (!homeheld) {
        if (buttonStates[BUTTON_SM_4] == BUTTON_LONG_PRESSED) {
          if (!yToggleHandled) {
            yToggle = !yToggle;
            yToggleHandled = true;
          }
        } else {
          yToggleHandled = false;
          if (actionNeeded[BUTTON_SM_4] == ACTION_SHORT_PRESS) {
            ReportData.Button |= Y_MASK_ON;
            pressStartTime[BUTTON_SM_4] = millis();
            actionNeeded[BUTTON_SM_4] = ACTION_SHORT_PRESS_HOLDING;
          } else if (actionNeeded[BUTTON_SM_4] == ACTION_SHORT_PRESS_HOLDING) {
            ReportData.Button |= Y_MASK_ON;
            if (millis() - pressStartTime[BUTTON_SM_4] >= 255)
              actionNeeded[BUTTON_SM_4] = ACTION_SHORT_RELEASE;
          } else if (actionNeeded[BUTTON_SM_4] == ACTION_SHORT_RELEASE) {
            actionNeeded[BUTTON_SM_4] = ACTION_NONE;
          }
        }
      } else {
        // homeheld: long press => momentary R3, short press => Y
        if (buttonStates[BUTTON_SM_4] == BUTTON_LONG_PRESSED) {
          ReportData.Button |= R3_MASK_ON;
        } else {
          if (actionNeeded[BUTTON_SM_4] == ACTION_SHORT_PRESS) {
            ReportData.Button |= Y_MASK_ON;
            pressStartTime[BUTTON_SM_4] = millis();
            actionNeeded[BUTTON_SM_4] = ACTION_SHORT_PRESS_HOLDING;
          } else if (actionNeeded[BUTTON_SM_4] == ACTION_SHORT_PRESS_HOLDING) {
            ReportData.Button |= Y_MASK_ON;
            if (millis() - pressStartTime[BUTTON_SM_4] >= 255)
              actionNeeded[BUTTON_SM_4] = ACTION_SHORT_RELEASE;
          } else if (actionNeeded[BUTTON_SM_4] == ACTION_SHORT_RELEASE) {
            actionNeeded[BUTTON_SM_4] = ACTION_NONE;
          }
        }
      }
    }
    // SHIFT_SM_1: L button (toggles ZL in default mode)
    else if (i == SHIFT_SM_1) {
      if (!homeheld) {
        // Default mode: short press => toggle ZL, long press => LB
        if (buttonStates[SHIFT_SM_1] == BUTTON_LONG_PRESSED) {
          ReportData.Button |= LB_MASK_ON;
        } else {
          // short press => toggle ZL
          if (actionNeeded[SHIFT_SM_1] == ACTION_SHORT_PRESS) {
            if (!shift1ToggleHandled) {
              shift1ZLToggle = !shift1ZLToggle;
              shift1ToggleHandled = true;
            }
            actionNeeded[SHIFT_SM_1] = ACTION_NONE;
          } else if (buttonStates[SHIFT_SM_1] == BUTTON_IDLE) {
            shift1ToggleHandled = false;
          }
        }
      } else {
        // Homeheld: short press => momentary ZL, long press => LB
        if (buttonStates[SHIFT_SM_1] == BUTTON_LONG_PRESSED) {
          ReportData.Button |= LB_MASK_ON;
        } else {
          if (actionNeeded[SHIFT_SM_1] == ACTION_SHORT_PRESS) {
            ReportData.Button |= ZL_MASK_ON;
            pressStartTime[SHIFT_SM_1] = millis();
            actionNeeded[SHIFT_SM_1] = ACTION_SHORT_PRESS_HOLDING;
          } else if (actionNeeded[SHIFT_SM_1] == ACTION_SHORT_PRESS_HOLDING) {
            ReportData.Button |= ZL_MASK_ON;
            if (millis() - pressStartTime[SHIFT_SM_1] >= 255) {
              actionNeeded[SHIFT_SM_1] = ACTION_SHORT_RELEASE;
            }
          } else if (actionNeeded[SHIFT_SM_1] == ACTION_SHORT_RELEASE) {
            actionNeeded[SHIFT_SM_1] = ACTION_NONE;
          }
        }
      }
    }
    // SHIFT_SM_2: R button (toggles ZR in default mode)
    else if (i == SHIFT_SM_2) {
      if (!homeheld) {
        // Default mode: short press => toggle ZR, long press => RB
        if (buttonStates[SHIFT_SM_2] == BUTTON_LONG_PRESSED) {
          ReportData.Button |= RB_MASK_ON;
        } else {
          // short press => toggle ZR
          if (actionNeeded[SHIFT_SM_2] == ACTION_SHORT_PRESS) {
            if (!shift2ToggleHandled) {
              shift2ZRToggle = !shift2ZRToggle;
              shift2ToggleHandled = true;
            }
            actionNeeded[SHIFT_SM_2] = ACTION_NONE;
          } else if (buttonStates[SHIFT_SM_2] == BUTTON_IDLE) {
            shift2ToggleHandled = false;
          }
        }
      } else {
        // Homeheld: short press => momentary ZR, long press => RB
        if (buttonStates[SHIFT_SM_2] == BUTTON_LONG_PRESSED) {
          ReportData.Button |= RB_MASK_ON;
        } else {
          if (actionNeeded[SHIFT_SM_2] == ACTION_SHORT_PRESS) {
            ReportData.Button |= ZR_MASK_ON;
            pressStartTime[SHIFT_SM_2] = millis();
            actionNeeded[SHIFT_SM_2] = ACTION_SHORT_PRESS_HOLDING;
          } else if (actionNeeded[SHIFT_SM_2] == ACTION_SHORT_PRESS_HOLDING) {
            ReportData.Button |= ZR_MASK_ON;
            if (millis() - pressStartTime[SHIFT_SM_2] >= 255) {
              actionNeeded[SHIFT_SM_2] = ACTION_SHORT_RELEASE;
            }
          } else if (actionNeeded[SHIFT_SM_2] == ACTION_SHORT_RELEASE) {
            actionNeeded[SHIFT_SM_2] = ACTION_NONE;
          }
        }
      }
    }
    // BUTTON_SM_6: HOME button (short press = HOME, long press toggles homeheld)
    else if (i == BUTTON_SM_6) {
      if (buttonStates[BUTTON_SM_6] == BUTTON_LONG_PRESSED) {
        if (!homeheldToggleHandled) {
          homeheld = !homeheld;
          homeheldToggleHandled = true;
        }
      } else {
        homeheldToggleHandled = false;
        if (actionNeeded[BUTTON_SM_6] == ACTION_SHORT_PRESS) {
          ReportData.Button |= HOME_MASK_ON;
          pressStartTime[BUTTON_SM_6] = millis();
          actionNeeded[BUTTON_SM_6] = ACTION_SHORT_PRESS_HOLDING;
        } else if (actionNeeded[BUTTON_SM_6] == ACTION_SHORT_PRESS_HOLDING) {
          ReportData.Button |= HOME_MASK_ON;
          if (millis() - pressStartTime[BUTTON_SM_6] >= 255)
            actionNeeded[BUTTON_SM_6] = ACTION_SHORT_RELEASE;
        } else if (actionNeeded[BUTTON_SM_6] == ACTION_SHORT_RELEASE) {
          actionNeeded[BUTTON_SM_6] = ACTION_NONE;
        }
      }
    }
    // BUTTON_SM_7: Altmode toggle
    else if (i == BUTTON_SM_7) {
      if (actionNeeded[BUTTON_SM_7] == ACTION_SHORT_PRESS) {
        altmode = !altmode;
        pressStartTime[BUTTON_SM_7] = millis();
        actionNeeded[BUTTON_SM_7] = ACTION_SHORT_PRESS_HOLDING;
      } else if (actionNeeded[BUTTON_SM_7] == ACTION_SHORT_PRESS_HOLDING) {
        if (millis() - pressStartTime[BUTTON_SM_7] >= 255)
          actionNeeded[BUTTON_SM_7] = ACTION_SHORT_RELEASE;
      } else if (actionNeeded[BUTTON_SM_7] == ACTION_SHORT_RELEASE) {
        actionNeeded[BUTTON_SM_7] = ACTION_NONE;
      }
    }
  }

  // In default mode, we apply persistent toggles for ZL, ZR, L3, and R3
  if (!homeheld) {
    if (shift1ZLToggle) ReportData.Button |= ZL_MASK_ON;
    if (shift2ZRToggle) ReportData.Button |= ZR_MASK_ON;
    if (aToggle)        ReportData.Button |= L3_MASK_ON;
    if (yToggle)        ReportData.Button |= R3_MASK_ON;
  }

  // Show homeheld status on onboard LED
  digitalWrite(pinOBLED, homeheld ? HIGH : LOW);
}

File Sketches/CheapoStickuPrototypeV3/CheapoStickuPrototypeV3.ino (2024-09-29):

#include "LUFAConfig.h"
#include <LUFA.h>
#include "Joystick.h"
#include <Wire.h>
#include <MPU6050.h>
#define BOUNCE_WITH_PROMPT_DETECTION
#include <Bounce2.h>

#define MILLIDEBOUNCE 1  // Debounce time in milliseconds
#define pinOBLED 17      // Onboard LED pin

#define joyX A0
#define joyY A1

MPU6050 mpu;           // Create an instance of the MPU6050
bool altmode = false;  // Define the altmode variable

byte buttonStatus[7];  // Adjusted size to match the number of buttons

// Define masks for the various button states
#define DPAD_NOTHING_MASK_ON 0x08
#define DPAD_UP_MASK_ON 0x00
#define DPAD_UPRIGHT_MASK_ON 0x01
#define DPAD_RIGHT_MASK_ON 0x02
#define DPAD_DOWNRIGHT_MASK_ON 0x03
#define DPAD_DOWN_MASK_ON 0x04
#define DPAD_DOWNLEFT_MASK_ON 0x05
#define DPAD_LEFT_MASK_ON 0x06
#define DPAD_UPLEFT_MASK_ON 0x07
#define A_MASK_ON 0x04
#define B_MASK_ON 0x02
#define X_MASK_ON 0x08
#define Y_MASK_ON 0x01
#define LB_MASK_ON 0x10
#define RB_MASK_ON 0x20
#define ZL_MASK_ON 0x40
#define ZR_MASK_ON 0x80
#define L3_MASK_ON 0x400
#define R3_MASK_ON 0x800
#define START_MASK_ON 0x200
#define SELECT_MASK_ON 0x100

// Button indices for buttonStatus array
#define BUTTON1 0
#define BUTTON2 1
#define BUTTON3 2
#define BUTTON4 3
#define BUTTON5 4
#define SHIFT1 5
#define SHIFT2 6

// Define pins for buttons and shifts
#define PIN_BUTTON1 4
#define PIN_BUTTON2 7
#define PIN_BUTTON3 9
#define PIN_BUTTON4 5
#define PIN_BUTTON5 15
#define PIN_SHIFT1 8
#define PIN_SHIFT2 6
#define PIN_ALT_MODE_0 0
#define PIN_ALT_MODE_1 1

Bounce button1 = Bounce();
Bounce button2 = Bounce();
Bounce button3 = Bounce();
Bounce button4 = Bounce();
Bounce button5 = Bounce();
Bounce shift1 = Bounce();
Bounce shift2 = Bounce();

// State machine indices for BUTTON1 to BUTTON4 and SHIFT1 to SHIFT2
#define BUTTON_SM_1 0
#define BUTTON_SM_2 1
#define BUTTON_SM_3 2
#define BUTTON_SM_4 3
#define SHIFT_SM_1 4
#define SHIFT_SM_2 5

// State machine for buttons
enum ButtonState { BUTTON_IDLE,
                   BUTTON_PRESSED,
                   BUTTON_LONG_PRESSED };
ButtonState buttonStates[6] = { BUTTON_IDLE, BUTTON_IDLE, BUTTON_IDLE, BUTTON_IDLE, BUTTON_IDLE, BUTTON_IDLE };

enum ButtonAction { ACTION_NONE,
                    ACTION_SHORT_PRESS,
                    ACTION_SHORT_PRESS_HOLDING,
                    ACTION_SHORT_RELEASE };
ButtonAction actionNeeded[6] = { ACTION_NONE, ACTION_NONE, ACTION_NONE, ACTION_NONE, ACTION_NONE, ACTION_NONE };

unsigned long buttonPressStartTime[6] = { 0, 0, 0, 0, 0, 0 };
unsigned long pressStartTime[6] = { 0, 0, 0, 0, 0, 0 };

void setupPins() {
  button1.attach(PIN_BUTTON1, INPUT_PULLUP);
  button2.attach(PIN_BUTTON2, INPUT_PULLUP);
  button3.attach(PIN_BUTTON3, INPUT_PULLUP);
  button4.attach(PIN_BUTTON4, INPUT_PULLUP);
  button5.attach(PIN_BUTTON5, INPUT_PULLUP);
  shift1.attach(PIN_SHIFT1, INPUT_PULLUP);
  shift2.attach(PIN_SHIFT2, INPUT_PULLUP);

  button1.interval(MILLIDEBOUNCE);
  button2.interval(MILLIDEBOUNCE);
  button3.interval(MILLIDEBOUNCE);
  button4.interval(MILLIDEBOUNCE);
  button5.interval(MILLIDEBOUNCE);
  shift1.interval(MILLIDEBOUNCE);
  shift2.interval(MILLIDEBOUNCE);

  pinMode(pinOBLED, OUTPUT);
  pinMode(PIN_ALT_MODE_0, INPUT_PULLUP);  // Set pin for altmode
  pinMode(PIN_ALT_MODE_1, INPUT_PULLUP);  // Set pin for altmode
  digitalWrite(pinOBLED, HIGH);
}

void setup() {
  setupPins();

  // Initialize MPU6050
  Wire.begin();
  mpu.initialize();

  if (!mpu.testConnection()) {
    // Connection failed, handle error
    while (true) {
      // Blink onboard LED to indicate error
      digitalWrite(pinOBLED, !digitalRead(pinOBLED));
      delay(500);
    }
  }

  SetupHardware();
  GlobalInterruptEnable();
}

void loop() {
  // Check altmode status
  if (digitalRead(PIN_ALT_MODE_0) == LOW) {
    altmode = true;
  } else if (digitalRead(PIN_ALT_MODE_1) == LOW) {
    altmode = false;
  }

  readAnalogStick();
  readMPU6050();  // Read accelerometer data
  readButtons();
  processButtons();
  HID_Task();
  USB_USBTask();
}


void readAnalogStick() {
  // Define deadzone threshold
  const int deadzone = 15;

  // Read analog values
  int xValue = analogRead(joyX);
  int yValue = analogRead(joyY);

  // Apply deadzone to xValue
  if (abs(xValue - 512) < deadzone) {  // Assuming 512 is the center value for the analog stick
    xValue = 512;                      // Set to neutral position
  }

  // Apply deadzone to yValue
  if (abs(yValue - 512) < deadzone) {  // Assuming 512 is the center value for the analog stick
    yValue = 512;                      // Set to neutral position
  }

  // Check if BUTTON5 is pressed
  if (buttonStatus[BUTTON5] == LOW) {  // If BUTTON5 is pressed
    // Map analog stick values to DPAD with inverted left/right
    if (xValue < 341) {    // Now this is Right
      if (yValue < 341) {  // Up-Right
        ReportData.HAT = DPAD_UPRIGHT_MASK_ON;
      } else if (yValue > 682) {  // Down-Right
        ReportData.HAT = DPAD_DOWNRIGHT_MASK_ON;
      } else {  // Straight Right
        ReportData.HAT = DPAD_RIGHT_MASK_ON;
      }
    } else if (xValue > 682) {  // Now this is Left
      if (yValue < 341) {       // Up-Left
        ReportData.HAT = DPAD_UPLEFT_MASK_ON;
      } else if (yValue > 682) {  // Down-Left
        ReportData.HAT = DPAD_DOWNLEFT_MASK_ON;
      } else {  // Straight Left
        ReportData.HAT = DPAD_LEFT_MASK_ON;
      }
    } else {               // Center X-axis
      if (yValue < 341) {  // Up
        ReportData.HAT = DPAD_UP_MASK_ON;
      } else if (yValue > 682) {  // Down
        ReportData.HAT = DPAD_DOWN_MASK_ON;
      } else {  // Neutral
        ReportData.HAT = DPAD_NOTHING_MASK_ON;
      }
    }

    // Center the specified joystick axes based on altmode
    if (altmode || buttonStatus[BUTTON5] == LOW) {
      // If altmode is true, center LX and LY
      ReportData.LX = 128;
      ReportData.LY = 128;
    } else {
      // If altmode is false, center RX and RY
      ReportData.RX = 128;
      ReportData.RY = 128;
    }
  } else {
    ReportData.HAT = DPAD_NOTHING_MASK_ON;

    // Map analog stick to standard functionality
    if (altmode) {
      // Map to LX and LY when altmode is true
      ReportData.LX = map(xValue, 0, 1023, 255, 0);  // Flipping directions
      ReportData.LY = map(yValue, 0, 1023, 0, 255);
    } else {
      // Map to RX and RY when altmode is false
      ReportData.RX = map(xValue, 0, 1023, 255, 0);  // Flipping directions
      ReportData.RY = map(yValue, 0, 1023, 0, 255);
    }
  }
}
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

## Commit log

2024-07-15 Initial Commit and Beginnings
    [3.3v Pro Micro Long-B_Cu.gbr, 3.3v Pro Micro Long-B_Mask.gbr, 3.3v Pro Micro Long-B_Paste.gbr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]
2024-07-17 Added Main PCB w Wii Connector
    [3.3v Pro Micro Wii Connector-B_Cu.gbr, 3.3v Pro Micro Wii Connector-B_Mask.gbr, 3.3v Pro Micro Wii Connector-B_Paste.gbr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]
2024-07-17 Almost Forgot KiCad
    [3.3v Pro Micro Wii Connector-B_Cu.gbr, 3.3v Pro Micro Wii Connector-B_Mask.gbr, 3.3v Pro Micro Wii Connector-B_Paste.gbr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]
2024-07-17 Restructured files and new script
    [3.3v Pro Micro Long-B_Cu.gbr, 3.3v Pro Micro Long-B_Mask.gbr, 3.3v Pro Micro Long-B_Paste.gbr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]
2024-07-27 Mini Boss edit
    [3.3v Pro Micro Long.kicad_pcb, 3.3v Pro Micro.kicad_pcb, 3.3v Pro Micro.kicad_sch]
2024-09-19 Updates with 3D Models
    [Logi Level Converter.x_t, MPU6050 v2.step, MPU6050 v2.stl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]
2024-09-27 Now with casing!
    [Back Plate Prime.stl, Front Plate Prime.stl, Joy Plate Prime.stl]
2024-09-27 Updated case files to be more ergonomic
    [Back Plate Prime (1).stl, Front Plate Prime (1).stl, Joy Plate Prime (1).stl]
2024-09-27 Opened Up Toggle Switch
    [Front Plate Prime.stl]
2025-02-24 Some updates to the layout
    I'm starting on board revision 3 so that I can add a couple more features and requested quality of life items.
    [QuickFinder V1.kicad_pcb, QuickFinder V1.kicad_sch, fullycustomcontrolle one hand Left Hand.kicad_pcb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]
2025-03-08 Updated the PCB files for V3
    WIll explain the layout in the next commit
    [Assembled Shell Render.stl, Back Plate Paragon.stl, Front Plate Paragon.stl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]
2025-03-13 Front Plate Done
    3D Print File Done for V4!
    [Front Plate to be Edited.stl, OneTrollaV4 Back Plate.stl, OneTrollaV4 Front Plate.stl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]
2025-03-14 Update OneTrollaV4 Back Plate.stl
    Fixed the dimensions of the backplate!
    [OneTrollaV4 Back Plate.stl]
